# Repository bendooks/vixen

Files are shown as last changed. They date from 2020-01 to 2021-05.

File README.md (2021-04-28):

Reverse engineering a VIC-20 RAM expansion
==========================================

This is a project to reverse engineer a Commodore VIC-20 memory expansion
from the old 8-bit computer days. This repository has several versions of
the board, a talk describing the process and related documentation.

The [talk](./talk/) directory contains all the relevant presentation files
and the [pcb](./pcb) directory has various PCB design projects (currently
mostly in Eagle 7).

There are some [pictures](https://photos.app.goo.gl/yPw7znJ7fA79bZMN6) of
both the original boards and my rebuilds.

Links
-----

- FOSDEM 2020 [talk](https://archive.fosdem.org/2020/schedule/event/retro_reverse_engineering_vic_20_cartridge/)
- Computing history [page](http://www.computinghistory.org.uk/det/32521/Vixen-Switchable-16K-RAM/)
- Retro-computing [page](https://www.retrocomputers.online/product/vixen-switchable-16k-ram/) includes [manual](https://www.retrocomputers.online/wp-content/uploads/2020/11/Vixen16kRAM.pdf)
- Commodore info [page](https://www.commodore-info.com/cartridge/item/vixen_16k/en/desktop)
- Nightfall crea [page](https://www.nightfallcrew.com/18/05/2010/vixen-switchable-16k-ram-for-commodore-vic-20/) includes detailed pictures.

License
-------

All work is under CC-BY-SA v4 unless otherwise stated.

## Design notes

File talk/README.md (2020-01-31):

FOSDEM talk material and tools
===============================

Here are the source files for the presentaton, first publically given at
FOSDEM 2020 (http://www.fosdem.org). They include the state machine and
timing diagram sources.

Datasheets
-----------

- 4416 DRAM (http://www.minuszerodegrees.net/ibm_ega_extra_ram/datasheet_TMS4416.pdf)

Tools
-----

Links to the tools used for diagrams

- state machine diagrams (https://state-machine-cat.js.org/)
- circuit simulation circuit.js (https://www.falstad.com/circuit/circuitjs.html)
- timing diagram tool (https://wavedrom.com/)

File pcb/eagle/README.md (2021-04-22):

Eagle PCB files
===============

These are the PCB file projects for the re-build of the original [vixen-copy](./vixen-copy/) and a new variant which is modified to support 64KiB-ish memory expansion [vixen-copy-64k](./vixen-copy-64ki)

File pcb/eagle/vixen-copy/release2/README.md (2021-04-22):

# Vixen Rebuild, Release 2

This is broken due to to soldermask issues with the edge connector. These
were meant to be fixed in the main project after release 1 but failed. A new
set of release files will be made from a similar version.

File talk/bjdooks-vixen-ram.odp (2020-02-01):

## Reverse engineering a VIC-20 expansion cartridge

Ben Dooks

ben.dooks@codethink.co.uk

ben@fluff.org

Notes: I started off in the days of the 8 bit computer, this is a bit of a trip back to the pre PC days Overview: - the hardware involved - quick overview of electrical interfaces - some techniques on how to reverse engineer

- © Copyright 2020 Ben Dooks
- Released under CC-BY-SA 4

## The VIC-20

- Released 1980
- 20KiB ROM
- 5KiB RAM
- $299 price

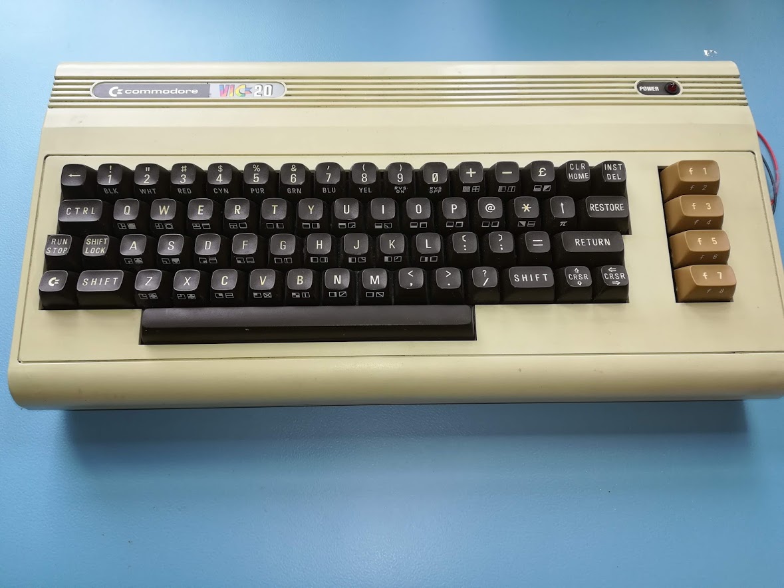
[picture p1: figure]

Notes: That’s around $778 in current money (approx £600) https://en.wikipedia.org/wiki/Commodore_VIC-20 5KiB of RAM leaves about 3300 bytes free for user

## The Vixen RAM expansion

- 16KiB RAM expansion (8bit x 16K)

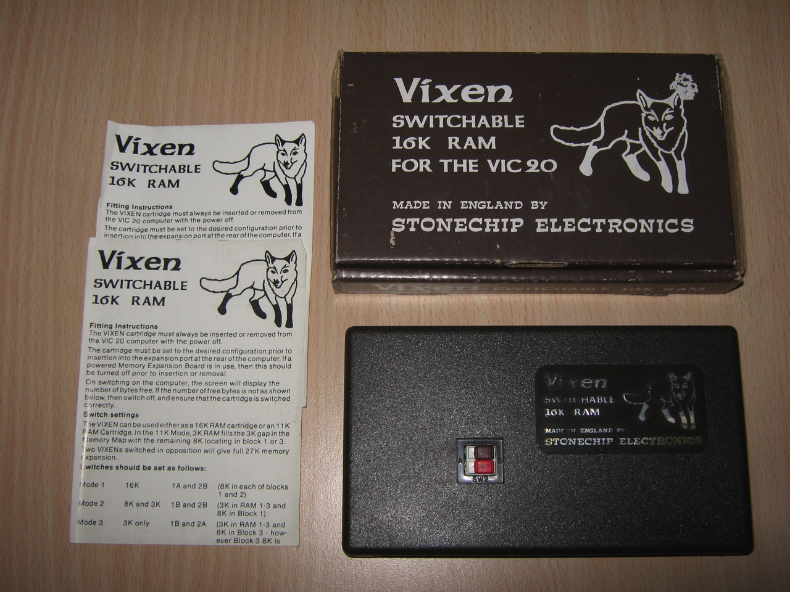
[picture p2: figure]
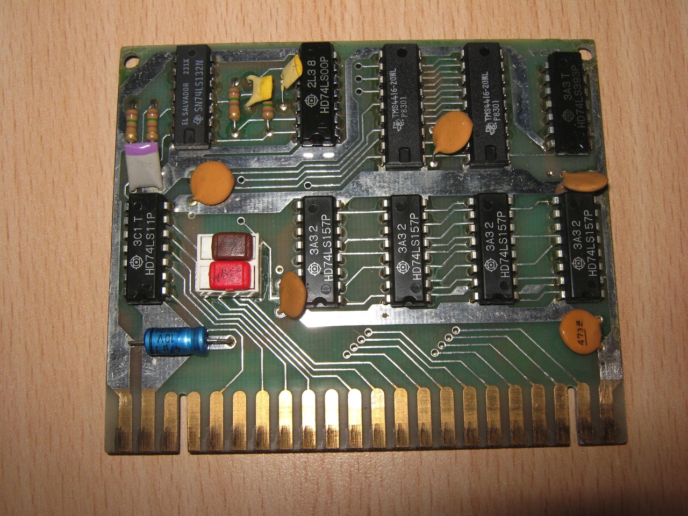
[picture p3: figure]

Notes: Source : https://www.nightfallcrew.com/18/05/2010/vixen-switchable-16k-ram-for-commodore-vic-20/ - found this device whilst browsing on line - would have loved this as a youth - no idea of the price of this device retailed - does not fill the memory map (but lots more)

## But why?

- My second ever computer.
- Browsing peripherals and found the Vixen RAM
  - And photos of the internals
  - But how did it work?
  - Is there sufficient information in the pictures?

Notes: -

## RAM

- Two main types
  - Dynamic (DRAM) and Static (SRAM)
- Most other expansions used static RAM
  - But the vixen uses dynamic RAM
  - And the circuit looks far too simple

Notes: - Many cartridges used easier SRAM

## Dynamic vs Static RAM

Dynamic RAM | Static RAM
Fast access time | Slower access time (250ns)
Multiplexed address bus | Simple address bus
External refresh cycle | No refresh cycle
Cheap | Expensive

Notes: Quick table for dynamic vs static - DRAM is much cheaper by about 8 times but requires multiplexed address and two stage address cycle. - I think 2-3 times cheaper per 1KiB, so for 16KiB this is a significant saving. - DRAM also needs an external refresh needs 128 rows refreshed every 4ms

## DRAM access states

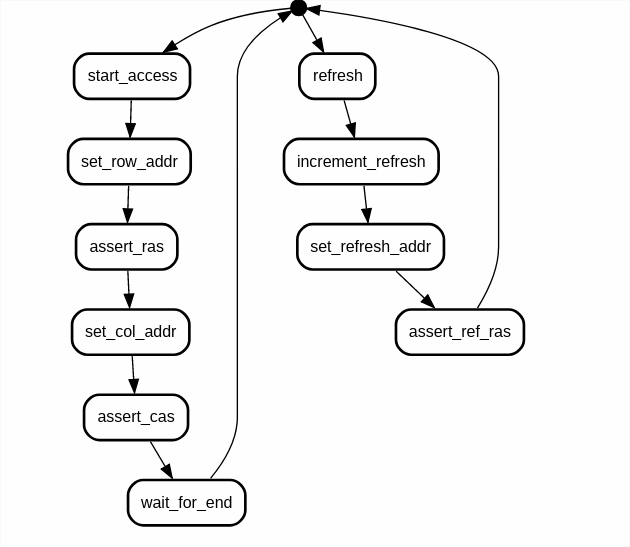
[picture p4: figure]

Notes: https://state-machine-cat.js.org/ Quick view of DRAM access states for normal data and for a refresh. In a modern system this would be a simple state machine you could build in a CPLD or FPGA but would require a 8-16 multiplied clock

## VIC-20 expansion bus

- Simple extension of 6502 main bus
  - 8 data and 13 address bits
  - Read and write
  - 9 pre-decoded chip selects
  - CPU clock
  - Soft and hard interrupt inputs

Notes: This is a fairly simple parallel bus Cycle time is about 1MHz (1000ns) - note there is no way to stall memory cycles for refresh

## 6502 Bus

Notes: Simplified diagram of 6502 memory access cycle Address is setup before the high cycle of the clock Data is read or written during high part of clock. The clock cycle is around 1MHz so approx 1000ns per cycle. This we will come back to later

## DRAM timing

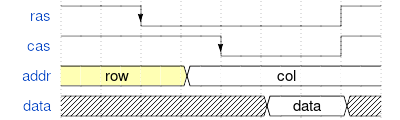
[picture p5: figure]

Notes: First is simple read/write single access. Second is RAS only refresh cycle of one row

## First thoughts

- The picture tells a lot
  - Components used
  - Basic track info
- All standard logic gates
  - Datasheets available
- Simple components
  - Resistors, capacitors
  - So no room for PLL/state machine

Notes: - most are simple logic gates - combinatorial logic and simple - full list in later slide - can sort of read some of the values from passives - list of ICs on the next slide - therefore no complicated state machine - certainly no PLL here

## Logic ICs

- 2x TMS4416 16K - 4bit DRAMS
- 1x 74LS393 – 2 x 4 bit binary counter
- 4x 74LS157 – 2 to 1 data mux (4 channels)
- 1x 74LS11 – 3 in AND gate (x3)
- 1x 74LS00 – 2 in NAND gate (x4)
- 1x 74LS132 – 2 schmitt NAND gate (x4)

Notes: So we have about 13 usable simple logic gates and bits for data muxing TMS4416 = 74LS157 = 89¢ 74LS393 = $2.49 Prices at Jan 1981 https://www.americanradiohistory.com/Archive-Poptronics/80s/1981/Poptronics-1981-01.pdf

## Simple start (address mux)

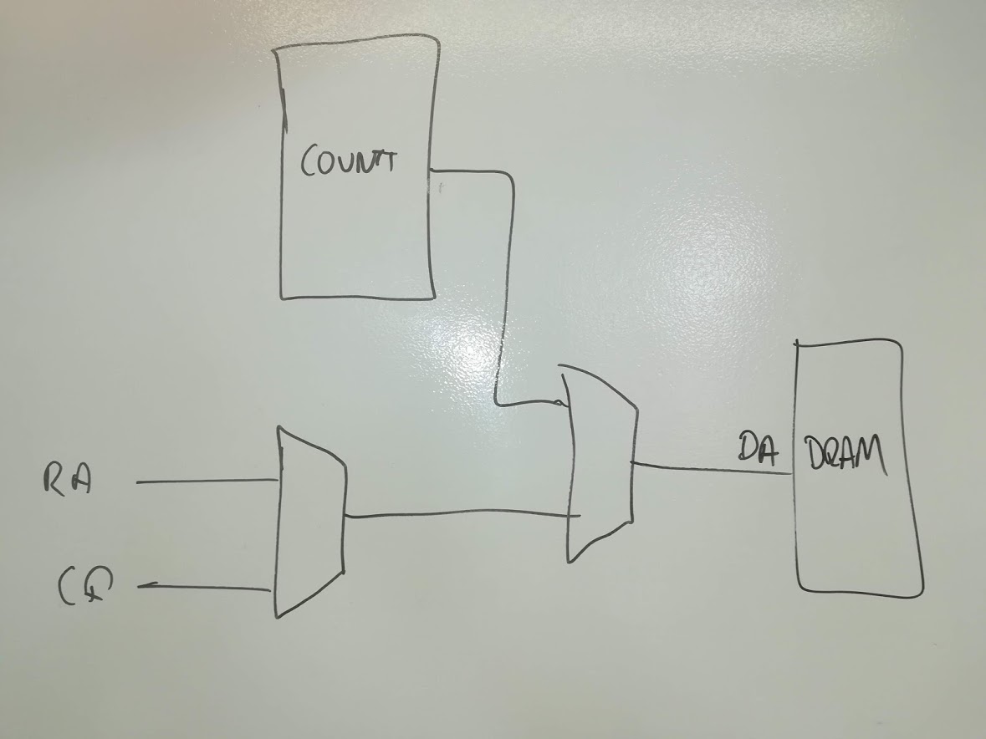
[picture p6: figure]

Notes: The 4-by-2 muxes are a good indication they are part of the address row/column and refresh. So it is quite easy to work out the few possibilities for the address mux. We’ll end up refreshing around 32 times more than we need to.

## So, refresh

- DRAM refresh cycle is around 400ns
  - Use inactive half of cycle to refresh
  - A bit more power
  - Normal VIC20 draws 16W anyway

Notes: Since the DRAM requires 400ns to refresh and we have 500ns of inactive cycle of the CPU clock we can simply refresh each cycle.
Worst case refresh current is 46mA per device, average is about 23mA.

## New state machine

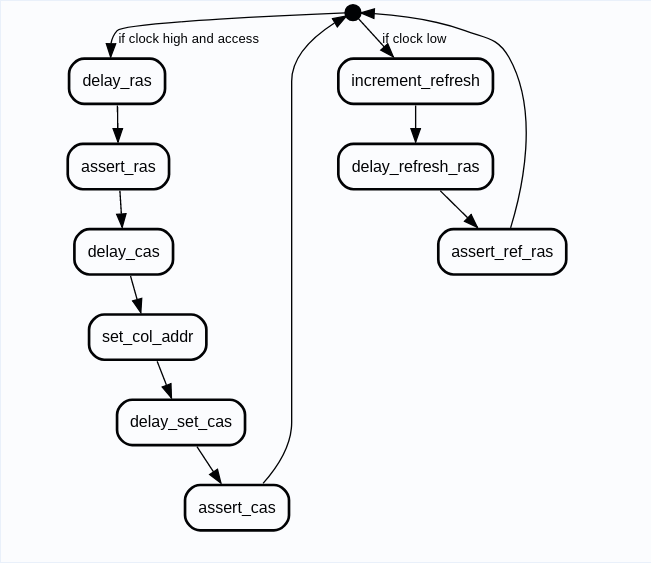
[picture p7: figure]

## First schematic attempt

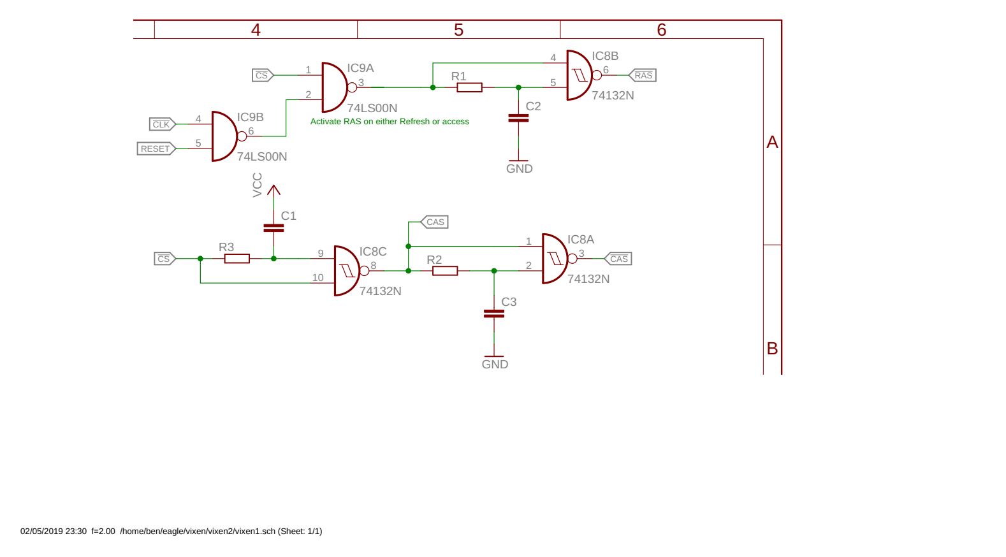
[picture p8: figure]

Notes: Simple logic gate RC delays to produce RAS/CAS from the clock and the access.

## The real hardware

- Track tracing
- Photograph and draw
- Multimeter
- And sneaky cap!

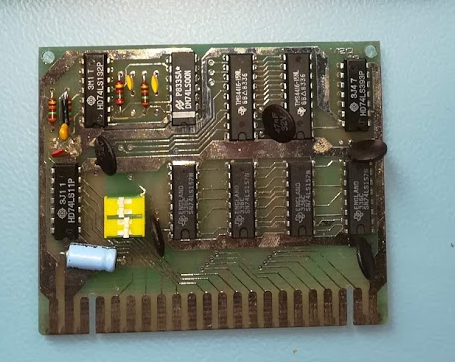
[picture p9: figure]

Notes: - searching find there is one on ebay → so bid and win The photo shows the hardware better and there is an extra capacitor hidden in the original.

## Tracing tracks

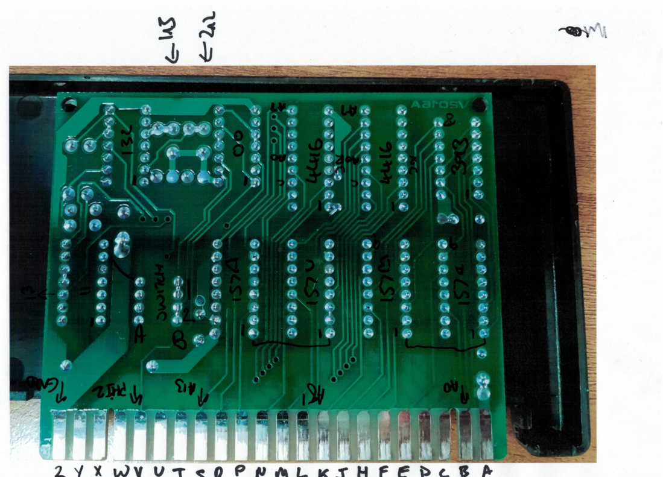
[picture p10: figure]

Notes: Take photo of underside Flip it so same way as looking down on board Add drawings of parts - use black marker to show components and connector details

## My clone board

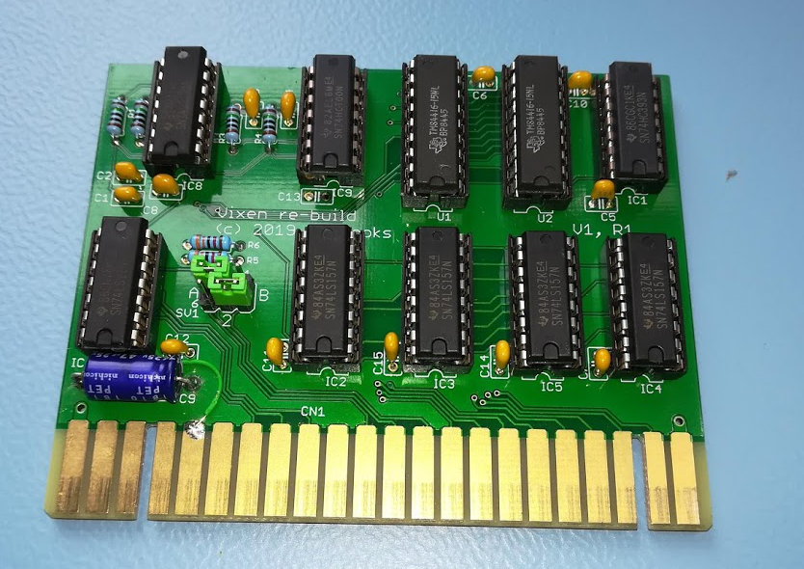
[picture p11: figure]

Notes: - spend two evenings using eagle - sent the gerber files to JLC - approx £30 in components - £13 for the PCBs

## How close was I

- Almost
- Refresh circuit wrong

## Simulation

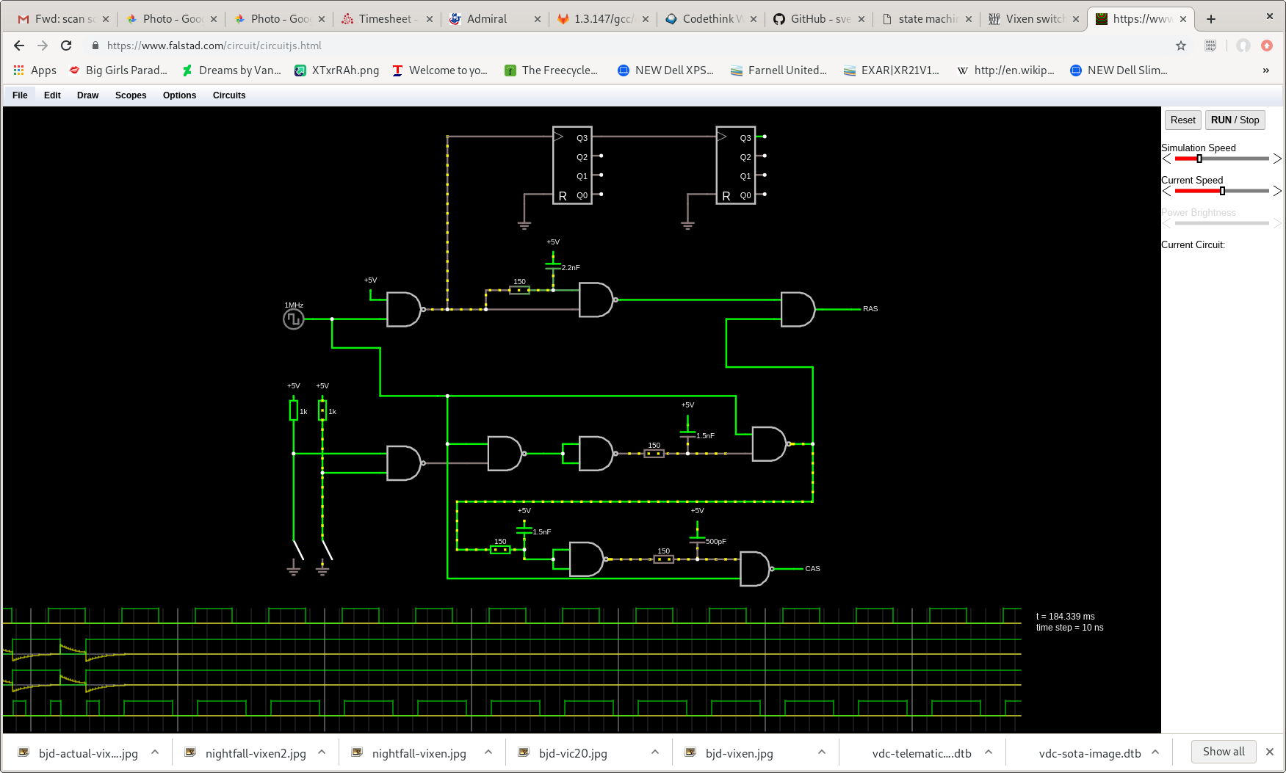
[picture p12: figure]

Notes: Should have thought of simulation sooner (Might have saved some money) This is circuit.js browser based simulation

## Future

- Try optimisation of design
  - It is very close to optimal
- Try with PLL and state machine
  - Simple PLL ICs were available
  - Possibly PLL + shift-register based state

## The end?

- Project files and documentation will be on:
  - https://github.com/bendooks/vixen
- Thank you. Any questions?

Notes: About 10 days of work into the reverse engineering

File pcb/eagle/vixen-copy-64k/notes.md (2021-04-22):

This is a version of the 16K Vixen that uses 64Kx4 DRAM parts to provide a full 35K memory map (not quite 64K ok).

To do this we have the issue of A14 and A15 not being provided directly by the expansion port, so these need to be re-created somehow. The A14 is probably the and of /BLK2 and /BLK3 and A15 could just equate to /BLK5. This combination should work to give the DRAM the necessary address lines.

We do not care about the mapping of address lines to DRAM addresses as we are the only ones generating them and the 64K parts are 8x8 addressed so there are no holes in the address mapping to worry about (see 16KiB version)

## Memory map

- /BLK1 is 0x2000-0x3fff (8KiB)
- /BLK2 is 0x4000-0x5fff (8KiB)
- /BLK3 is 0x6000-0x7fff (8KiB)
- /BLK5 is 0xA000.0xBFFF (8KiB)
- /RAM1../RAM3 are all in hte 0x400.0xfff lines

## Notes

- IA14/A8 swapped for easier routing

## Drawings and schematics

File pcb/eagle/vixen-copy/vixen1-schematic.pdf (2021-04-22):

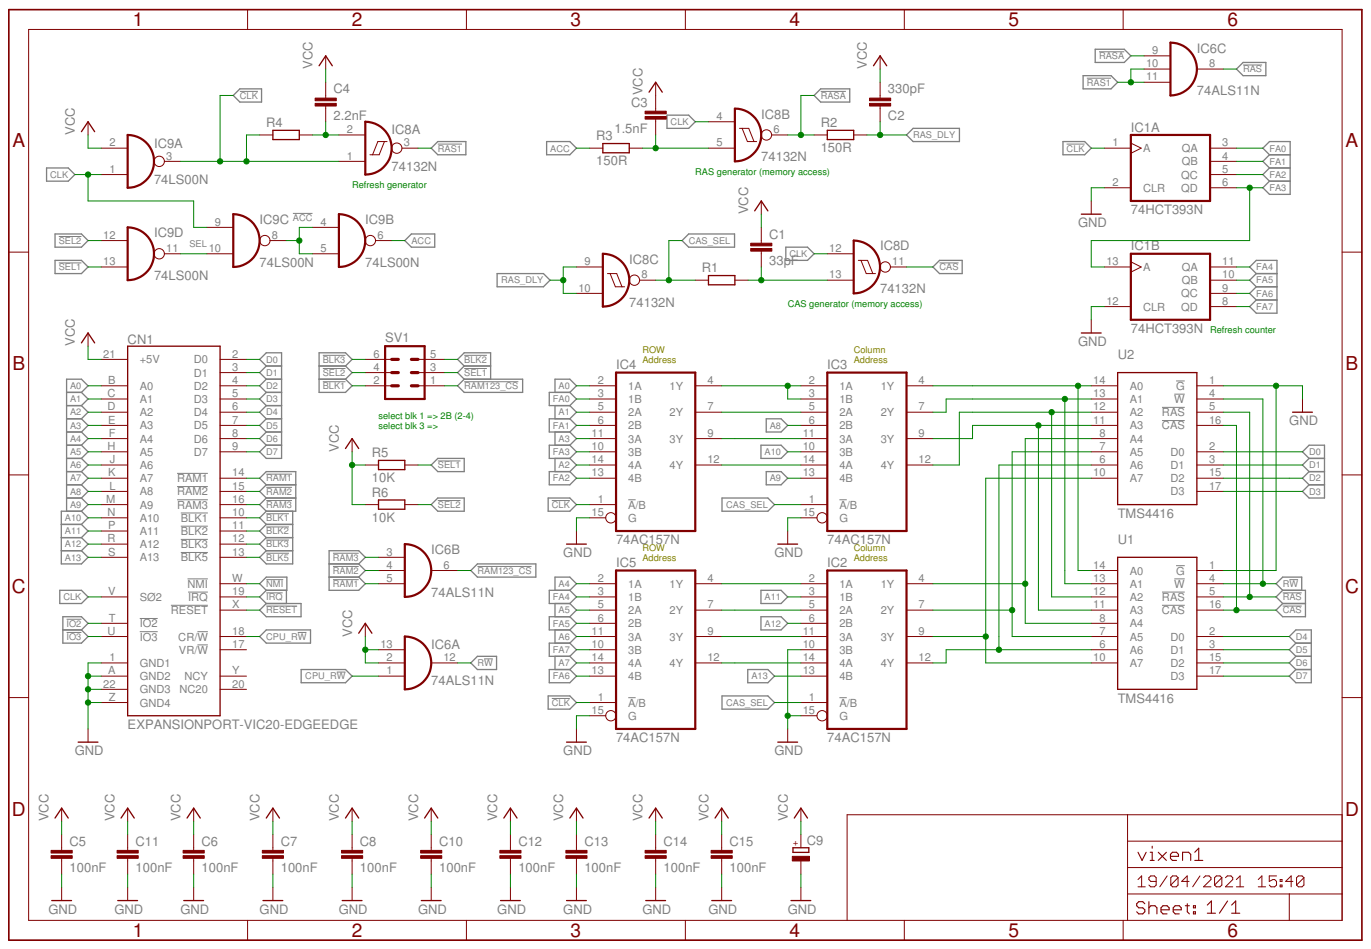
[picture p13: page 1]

11 | RAS

select blk 1 => 2B (2-4) select blk 3 =>

A12 R | BLK2 12 BLK5

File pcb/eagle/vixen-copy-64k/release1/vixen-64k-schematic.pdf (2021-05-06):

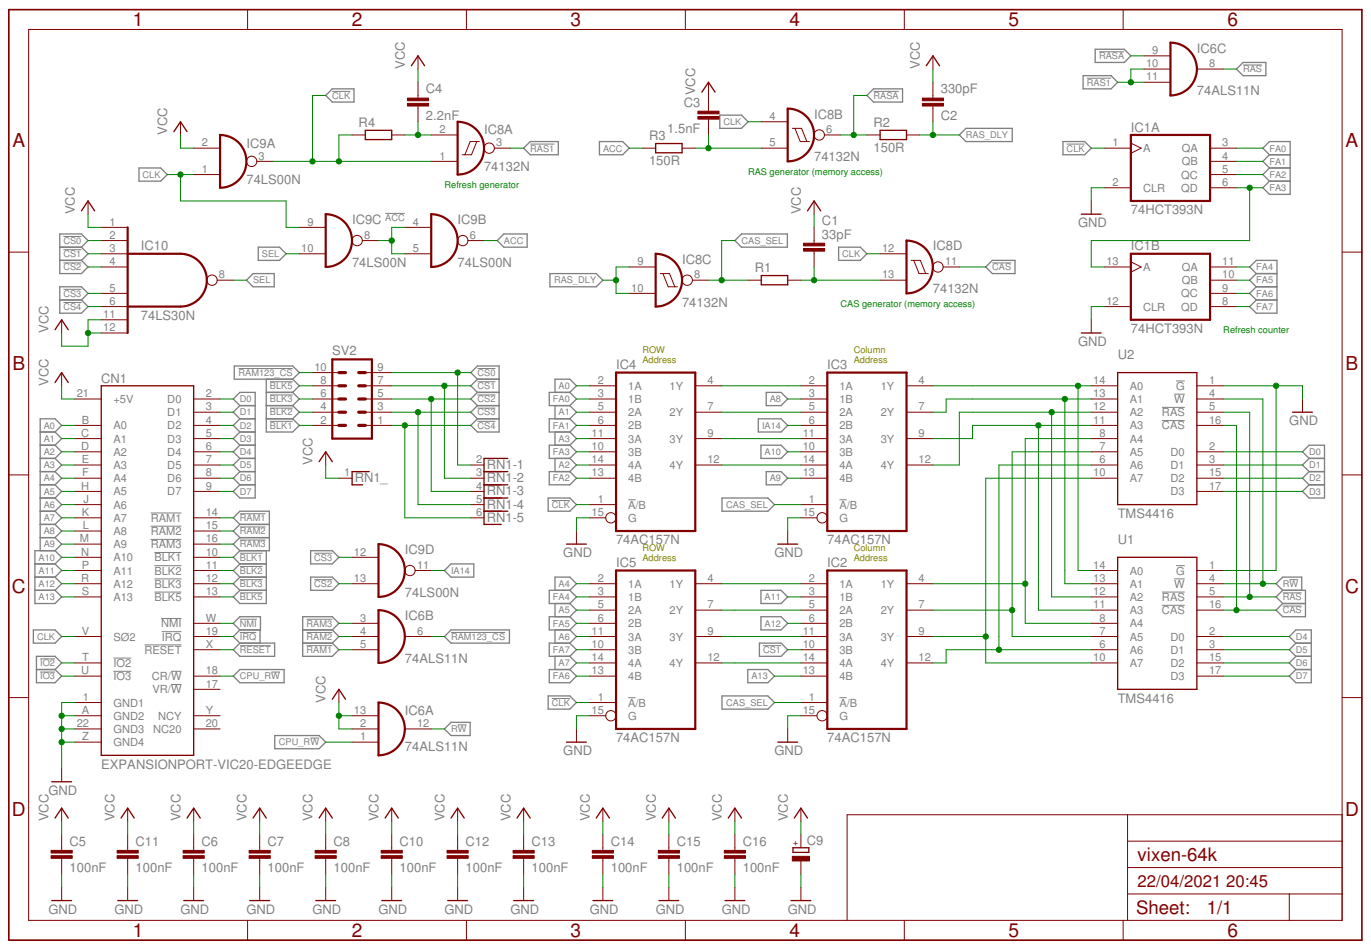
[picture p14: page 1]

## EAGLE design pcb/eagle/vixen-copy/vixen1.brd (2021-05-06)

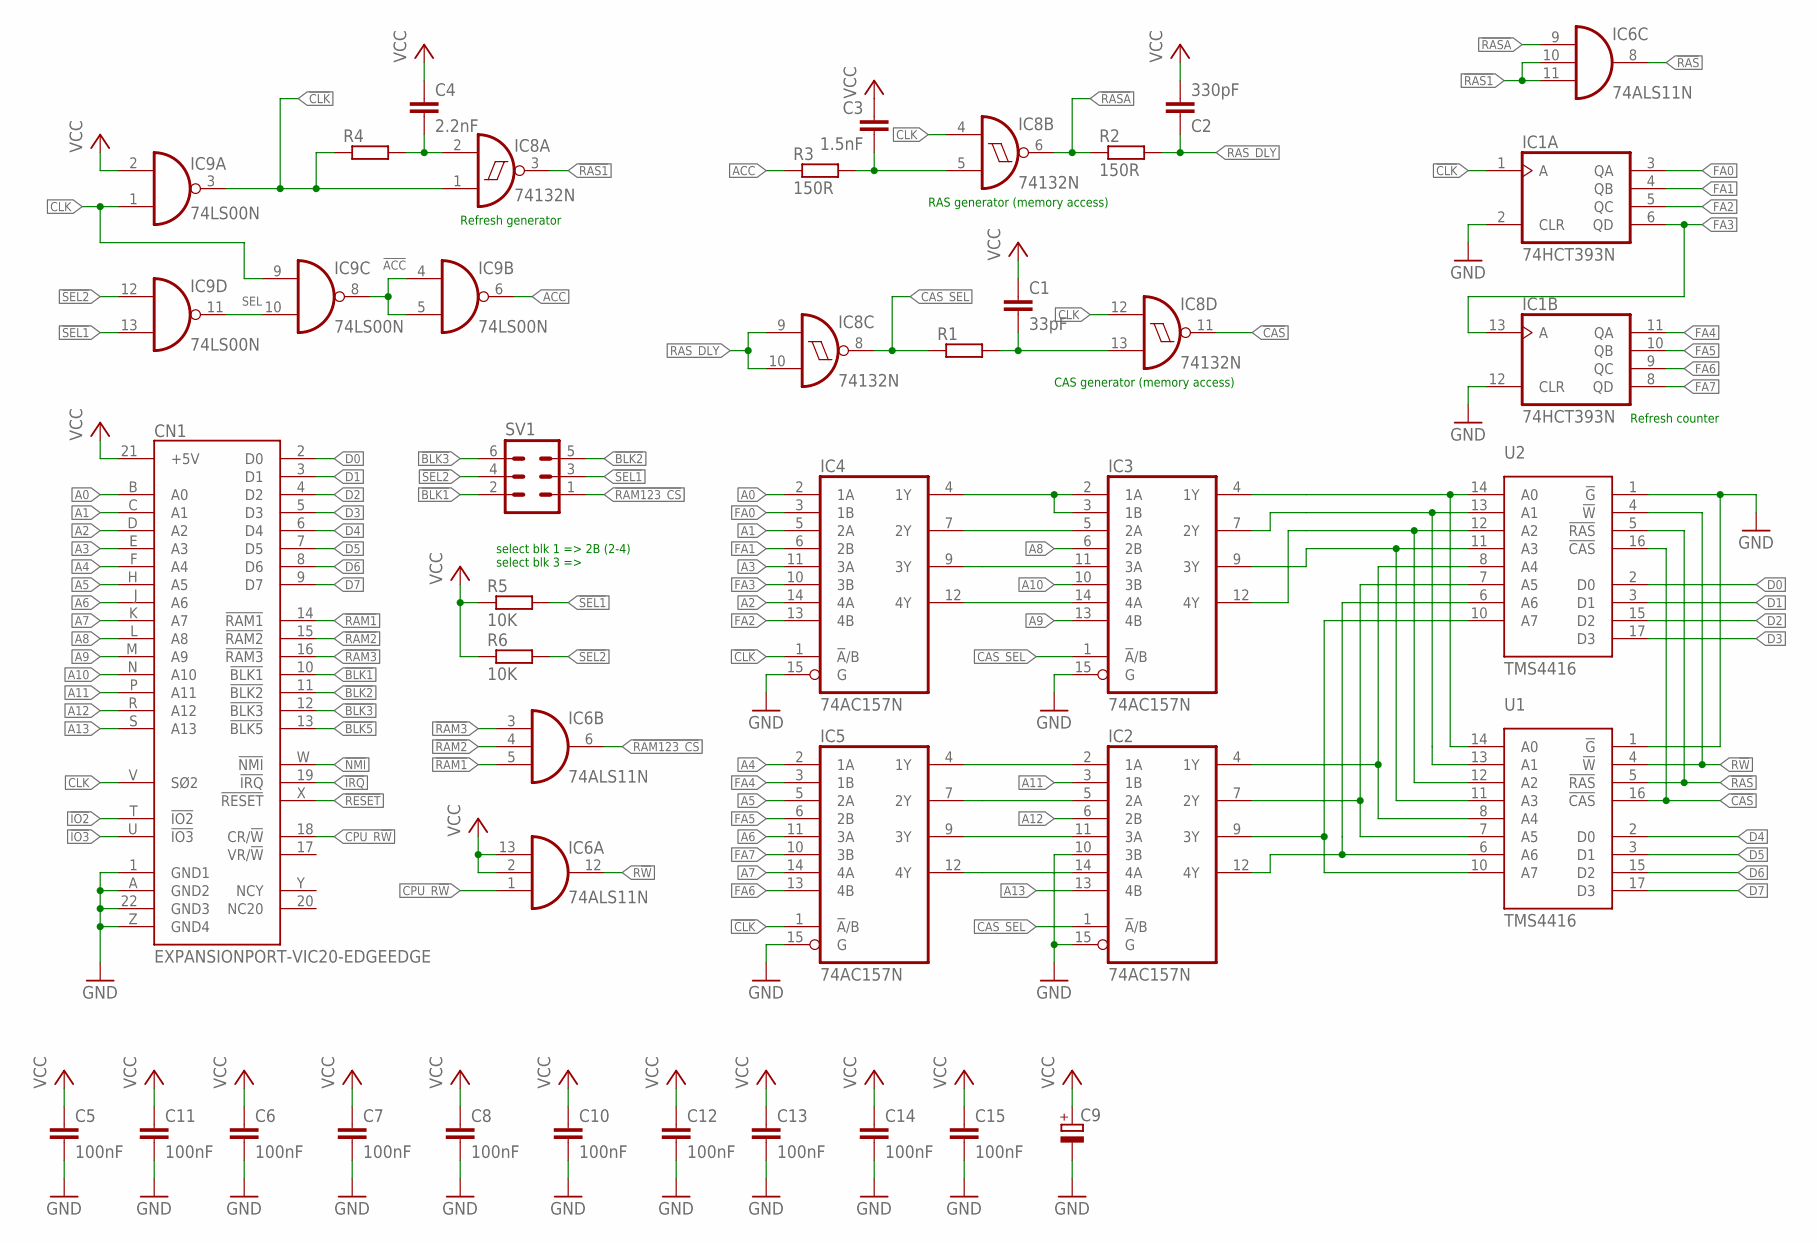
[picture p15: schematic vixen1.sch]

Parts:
C1: 33pF; C025-025X050
C2: 330pF; C025-025X050
C3: 1.5nF; C025-025X050
C4: 2.2nF; C025-025X050
C5, C6, C7, C8, C10, C11, C12, C13, C14, C15: 100nF; C025-025X050
C9: CPOL-EUE15-5AXIAL; E15-5
CN1: EXPANSIONPORT-VIC20-EDGEEDGE; UPS44EDGE
IC1: 74HCT393N; DIL14
IC2, IC3, IC4, IC5: 74AC157N; DIL16
IC6: 74ALS11N; DIL14
IC8: 74132N; DIL14
IC9: 74LS00N; DIL14
R1, R4: R-EU_0204/7; 0204/7
R2, R3: 150R; 0204/7
R5, R6: 10K; 0204/7
SV1: MA03-2
U1, U2: TMS4416; DIL18

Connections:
!ACC: IC9.4 (I0), IC9.5 (I1), IC9.8 (O)
!BLK1: CN1.10 (!BLK1), SV1.2
!BLK2: CN1.11 (!BLK2), SV1.5
!BLK3: CN1.12 (!BLK3), SV1.6
!BLK5: CN1.13 (!BLK5)
!CAS: IC8.11 (O), U1.16 (!CAS), U2.16 (!CAS)
!CLK: IC1.1 (A), IC4.1 (!A!/B), IC5.1 (!A!/B), IC8.1 (I0), IC9.3 (O), R4.1
!IO2: CN1.T (!IO2)
!IO3: CN1.U (!IO3)
!IRQ: CN1.19 (!IRQ)
!NMI: CN1.W (!NMI)
!RAM1: CN1.14 (!RAM1), IC6.5 (I2)
!RAM2: CN1.15 (!RAM2), IC6.4 (I1)
!RAM3: CN1.16 (!RAM3), IC6.3 (I0)
!RAM123_CS: IC6.6 (O), SV1.1
!RAS: IC6.8 (O), U1.5 (!RAS), U2.5 (!RAS)
!RAS1: IC6.10 (I1), IC6.11 (I2), IC8.3 (O)
!RASA: IC6.9 (I0), IC8.6 (O), R2.1
!RESET: CN1.X (!RESET)
!SEL1: IC9.13 (I1), R5.2, SV1.3
!SEL2: IC9.12 (I0), R6.2, SV1.4
A0: CN1.B (A0), IC4.2 (1A)
A1: CN1.C (A1), IC4.5 (2A)
A2: CN1.D (A2), IC4.14 (4A)
A3: CN1.E (A3), IC4.11 (3A)
A4: CN1.F (A4), IC5.2 (1A)
A5: CN1.H (A5), IC5.5 (2A)
A6: CN1.J (A6), IC5.11 (3A)
A7: CN1.K (A7), IC5.14 (4A)
A8: CN1.L (A8), IC3.6 (2B)
A9: CN1.M (A9), IC3.13 (4B)
A10: CN1.N (A10), IC3.10 (3B)
A11: CN1.P (A11), IC2.3 (1B)
A12: CN1.R (A12), IC2.6 (2B)
A13: CN1.S (A13), IC2.13 (4B)
ACC: IC9.6 (O), R3.1
CAS_RC: C1.2, IC8.13 (I1), R1.2
CAS_RC1: C4.2, IC8.2 (I1), R4.2
CAS_SEL: IC2.1 (!A!/B), IC3.1 (!A!/B), IC8.8 (O), R1.1
CLK: CN1.V (SØ2), IC8.4 (I0), IC8.12 (I0), IC9.1 (I0), IC9.9 (I0)
CPU_R!W: CN1.18 (CR/!W), IC6.1 (I0)
D0: CN1.2 (D0), U2.2 (D0)
D1: CN1.3 (D1), U2.3 (D1)
D2: CN1.4 (D2), U2.15 (D2)
D3: CN1.5 (D3), U2.17 (D3)
D4: CN1.6 (D4), U1.2 (D0)
D5: CN1.7 (D5), U1.3 (D1)
D6: CN1.8 (D6), U1.15 (D2)
D7: CN1.9 (D7), U1.17 (D3)
FA0: IC1.3 (QA), IC4.3 (1B)
FA1: IC1.4 (QB), IC4.6 (2B)
FA2: IC1.5 (QC), IC4.13 (4B)
FA3: IC1.6 (QD), IC1.13 (A), IC4.10 (3B)
FA4: IC1.11 (QA), IC5.3 (1B)
FA5: IC1.10 (QB), IC5.6 (2B)
FA6: IC1.9 (QC), IC5.13 (4B)
FA7: IC1.8 (QD), IC5.10 (3B)
GND: C5.2, C6.2, C7.2, C8.2, C9.-, C10.2, C11.2, C12.2, C13.2, C14.2, C15.2, CN1.1 (GND1), CN1.22 (GND3), CN1.A (GND2), CN1.Z (GND4), IC1.2 (CLR), IC1.7 (GND), IC1.12 (CLR), IC2.8 (GND), IC2.10 (3B), IC2.15 (G), IC3.8 (GND), IC3.15 (G), IC4.8 (GND), IC4.15 (G), IC5.8 (GND), IC5.15 (G), IC6.7 (GND), IC8.7 (GND), IC9.7 (GND), U1.1 (!G), U1.18 (GND), U2.1 (!G), U2.18 (GND)
R!W: IC6.12 (O), U1.4 (!W), U2.4 (!W)
RA0: IC3.4 (1Y), U1.14 (A0), U2.14 (A0)
RA1: IC3.7 (2Y), U1.13 (A1), U2.13 (A1)
RA2: IC3.12 (4Y), U1.12 (A2), U2.12 (A2)
RA3: IC3.9 (3Y), U1.11 (A3), U2.11 (A3)
RA4: IC2.4 (1Y), U1.8 (A4), U2.8 (A4)
RA5: IC2.7 (2Y), U1.7 (A5), U2.7 (A5)
RA6: IC2.12 (4Y), U1.6 (A6), U2.6 (A6)
RA7: IC2.9 (3Y), U1.10 (A7), U2.10 (A7)
RAS_DLY: C2.1, IC8.9 (I0), IC8.10 (I1), R2.2
RAS_RC1: C3.2, IC8.5 (I1), R3.2
ROW0: IC3.2 (1A), IC3.3 (1B), IC4.4 (1Y)
ROW1: IC3.5 (2A), IC4.7 (2Y)
ROW2: IC3.14 (4A), IC4.12 (4Y)
ROW3: IC3.11 (3A), IC4.9 (3Y)
ROW4: IC2.2 (1A), IC5.4 (1Y)
ROW5: IC2.5 (2A), IC5.7 (2Y)
ROW6: IC2.14 (4A), IC5.12 (4Y)
ROW7: IC2.11 (3A), IC5.9 (3Y)
SEL: IC9.10 (I1), IC9.11 (O)
VCC: C1.1, C2.2, C3.1, C4.1, C5.1, C6.1, C7.1, C8.1, C9.+, C10.1, C11.1, C12.1, C13.1, C14.1, C15.1, CN1.21 (+5V), IC1.14 (VCC), IC2.16 (VCC), IC3.16 (VCC), IC4.16 (VCC), IC5.16 (VCC), IC6.2 (I1), IC6.13 (I2), IC6.14 (VCC), IC8.14 (VCC), IC9.2 (I1), IC9.14 (VCC), R5.1, R6.1, U1.9 (VCC), U2.9 (VCC)

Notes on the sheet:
select blk 1 => 2B (2-4) select blk 3 =>
Refresh generator
RAS generator (memory access)
CAS generator (memory access)
Refresh counter

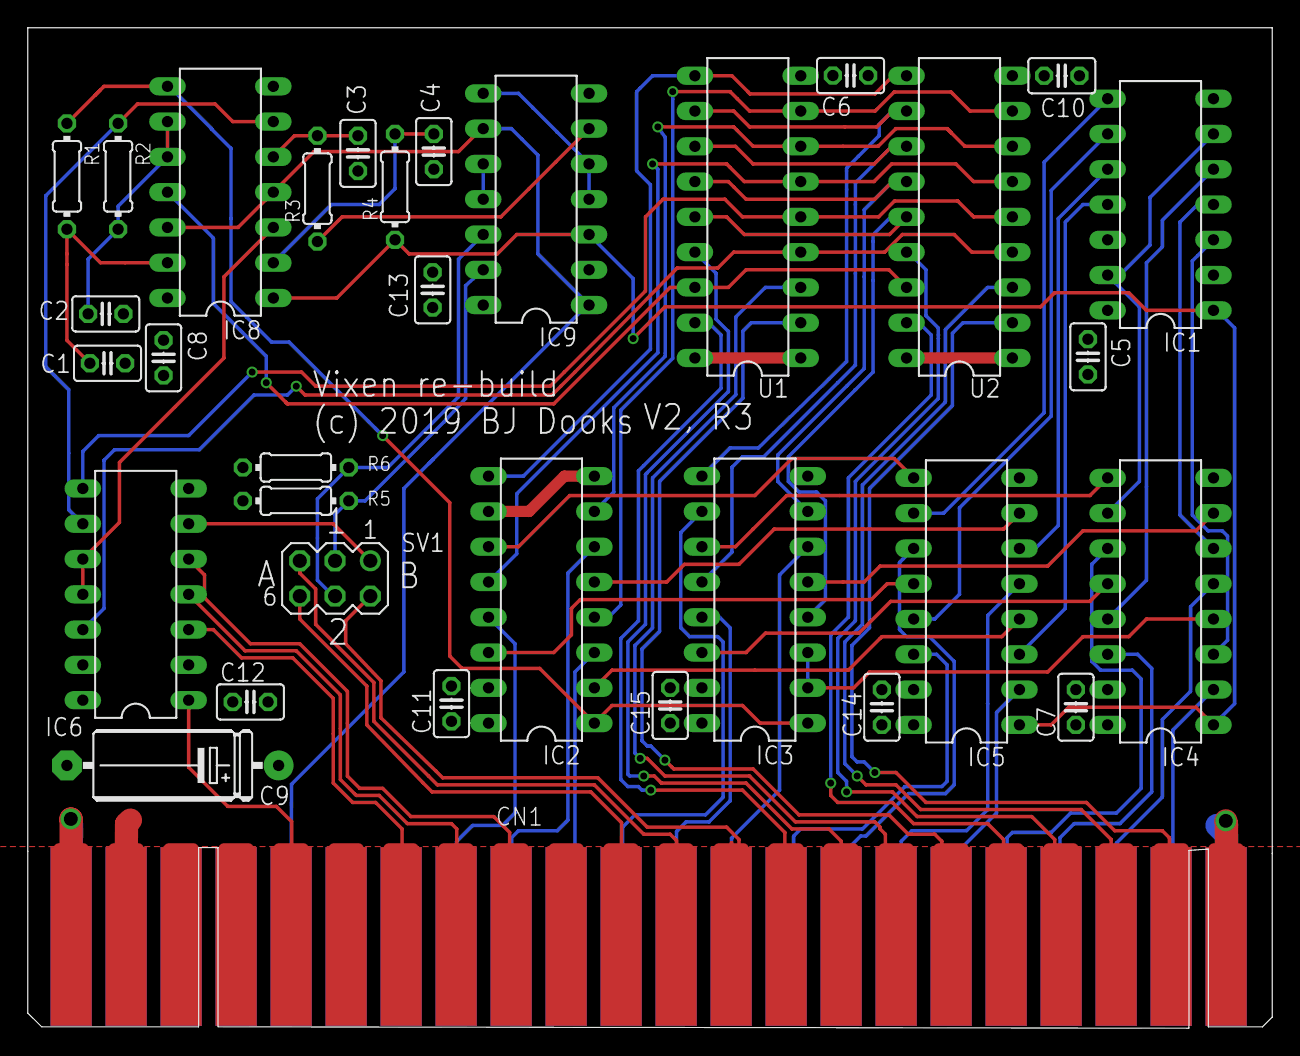
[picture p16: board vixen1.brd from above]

Board: 2 copper layers, 89.6 x 72.0 mm, 33 parts (0 on the bottom side), 73 nets.

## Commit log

2020-01-26 Import eagle files from building real board
    [vixen1.brd, vixen1.sch]
2020-01-26 PCB release 1 manufacutring files
    [vixen1.GBL, vixen1.GBO, vixen1.GBP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]
2020-01-31 talk: add circuitjs reference
2021-04-19 add BLK5 to netlist
    [vixen1.brd, vixen1.sch]
2021-04-19 fix pcb back version text to v2,r1
    [vixen1.brd]
2021-04-19 v2r1 of the pcb
    [vixen1.GBL, vixen1.GBO, vixen1.GBP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]
2021-04-22 initial work on 64KiB(ish) version of Vixen
    [vixen1.brd, vixen1.sch]
2021-04-22 Fix t-stop and v-stop layers to avoid soldermask on edge connector and incremen version
    [vixen1.brd]
2021-04-22 Add schematic printout to avoid having to load eagle
2021-04-22 updated 64k version schematic to fit in frame
    [vixen1.sch]
2021-04-22 add schematic pdf, rename project files to vixen-64k.{sch,brd}
    [vixen-64k.brd, vixen-64k.sch]
2021-05-06 vixen-64k: silkscreen updates and minor routing
    [vixen-64k.brd]
2021-05-06 minor soldermask updates, remove silkscreen out of board area
    [vixen-64k.brd]
2021-05-06 vixen-64k print final schematic
2021-05-06 vixen-64k: release1 data
    [vixen-64k.GBL, vixen-64k.GBO, vixen-64k.GBP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]
2021-05-06 vixen: minor pcb updates for v2,r3
    [vixen1.brd]

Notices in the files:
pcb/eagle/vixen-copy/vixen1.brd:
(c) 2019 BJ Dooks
